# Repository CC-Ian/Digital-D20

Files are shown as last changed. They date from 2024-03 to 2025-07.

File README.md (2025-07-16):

# Big Electronic D20

This project began several years ago, before pixel dice became widely available. Inspired by existing designs but aiming for something unique, this marks my first foray into PCB art. By adding artwork to the solder mask layer, the FR4 substrate is exposed, allowing light to shine through. Combined with a 3D-printed frame, a mainboard featuring LEDs, and an IMU, the result is a visually striking D20 that comes to life when rolled.

## Showcase

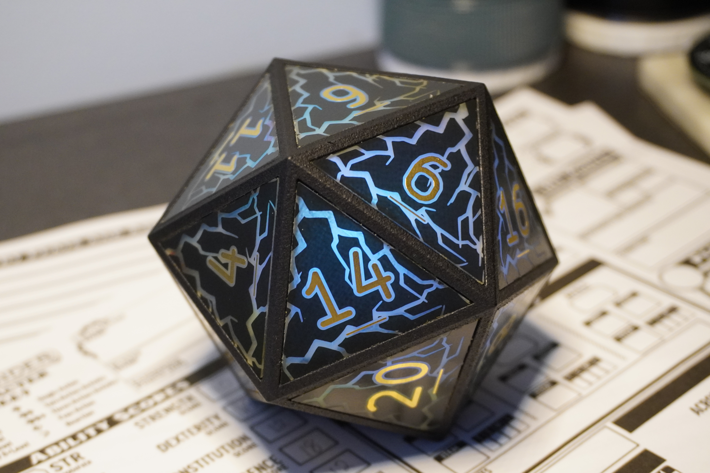
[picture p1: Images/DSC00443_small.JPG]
Atop a Character Sheet

Green Lightning Effect
Pink Lightning Effect

## Faces

- Each face is an equilateral triangle, 1.5" per edge.
- Single-sided PCBs with gold-plated numbers.
- Solder mask is relieved around each number for clear illumination.
- Lightning patterns are masked out for added visual interest.
- Designs were refined following prototype testing with various patterns.

## Frame

- Constructed from MJF-printed nylon in an icosahedral shape.
- Features inset shelves for gluing PCB faces.
- Includes cut-outs along two opposing spokes to accommodate the rectangular mainboard.

## Mainboard

- STM32L412KB microcontroller.
- LIS2DW12 MEMS IMU.
- 32 addressable LEDs.
- Voltage regulators and LiPo battery charging circuitry.
- Ultra-low power design: enters deep sleep mode when not in use.

### Operation

- The IMU detects motion, waking the microcontroller.
- LEDs activate and display a lightning animation while the die is in motion.
- The IMU is regularly polled during animation.
- When the die comes to rest, a final measurement determines the top face using cosine similarity.
- The face value determines the display color: pure red for 1, pure green for 20, with a linear gradient for intermediate values.
- The color is shown for a few seconds before returning to sleep mode.

### Power Consumption

- At rest: ~5μA, yielding a theoretical shelf life of ~5 years with a 400mAh battery.
- During operation: ~50mA, for a theoretical runtime of ~10 hours.
- Designed for intermittent use, suitable for multiple gaming sessions per charge.

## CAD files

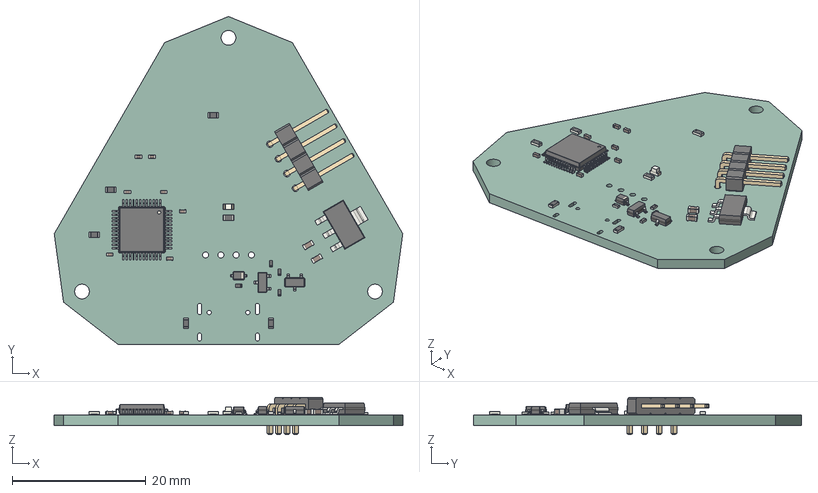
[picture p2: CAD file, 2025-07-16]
BaseStation/BaseStation.step
52.1 x 49.0 x 5.54 mm
R_0402_1005Metric x 4
C_0402_1005Metric x 7
R_0603_1608Metric x 6
C_0603_1608Metric x 2
LED_0603_1608Metric
SOT_223
SOT_23 x 2
LQFP_48_7x7mm_P05mm
D_SOD_323
PinHeader_1x04_P254mm_Horizontal
_autosave-BaseStation_PCB

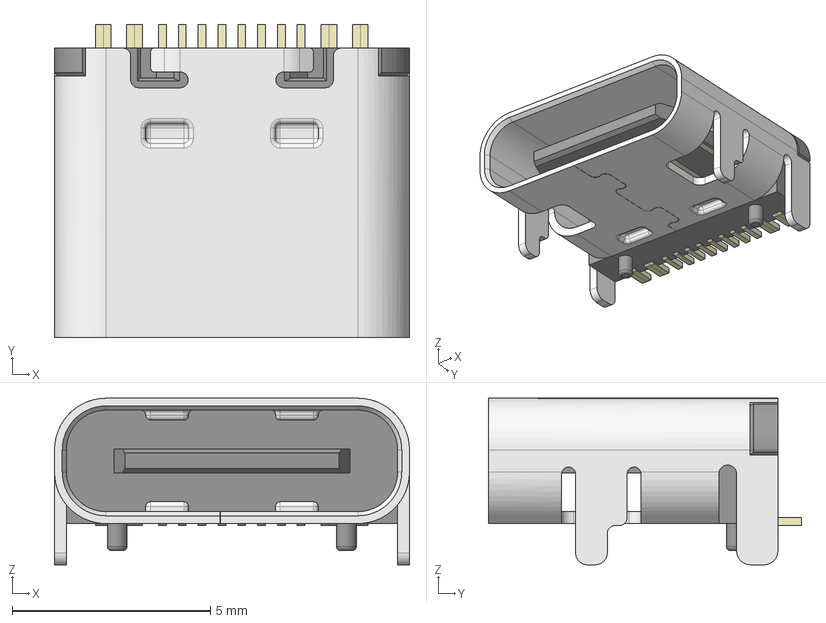
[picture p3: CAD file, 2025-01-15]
BaseStation/BaseStation/HRO_TYPE-C-31-M-12.step
8.95 x 7.90 x 4.20 mm

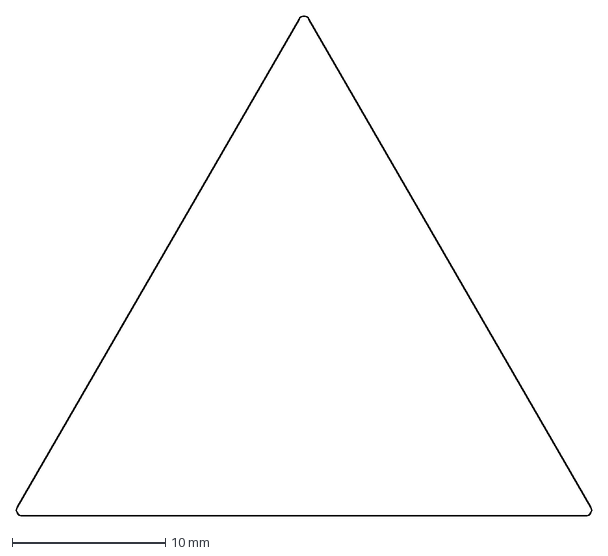
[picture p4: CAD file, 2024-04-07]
Faces/Tile Outline 1.5.dxf
37.6 x 32.6 mm

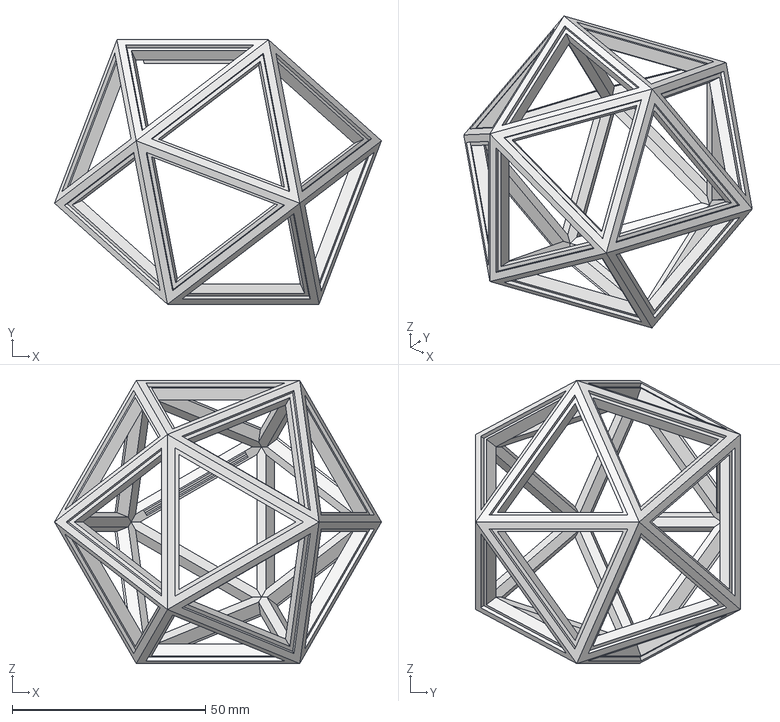
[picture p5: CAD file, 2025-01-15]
Frame/Electronic D20 Final.stp
84.7 x 68.5 x 73.3 mm

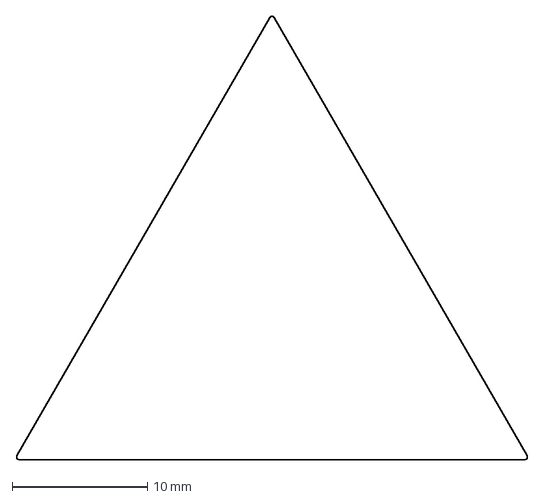
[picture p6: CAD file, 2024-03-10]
Mainboard/triangle tile outline.dxf
37.8 x 32.8 mm

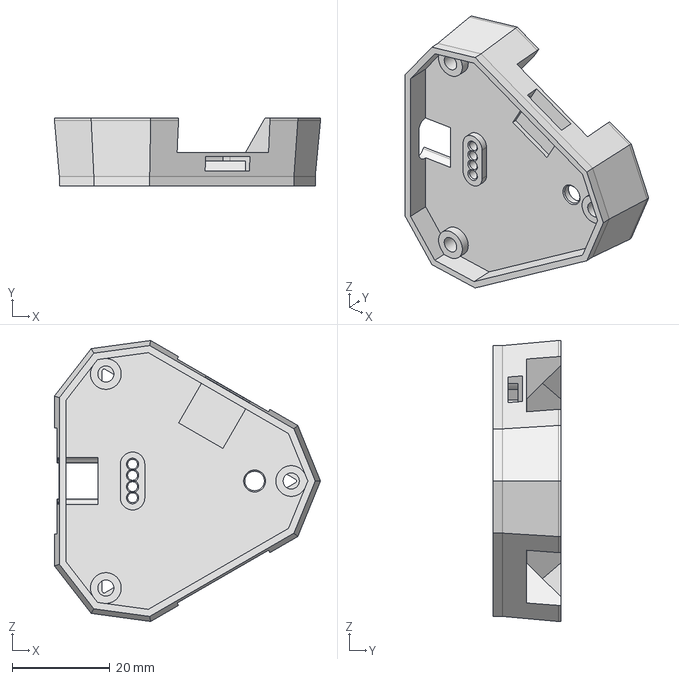
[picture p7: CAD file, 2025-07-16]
BaseStation/Base Station V2.step
54.5 x 14.0 x 57.5 mm

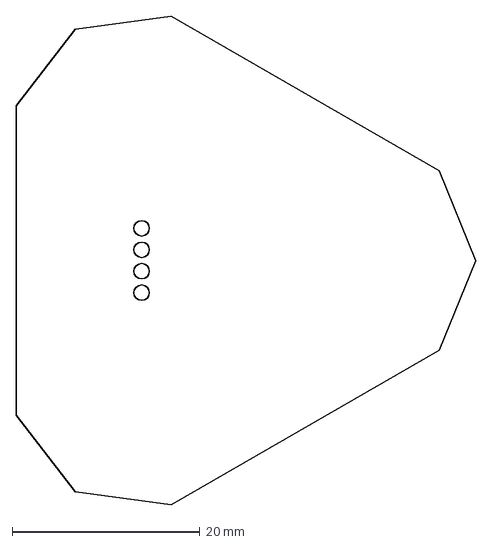
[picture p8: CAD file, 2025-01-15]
BaseStation/BaseStation/Board Outline.dxf
49.0 x 52.1 mm

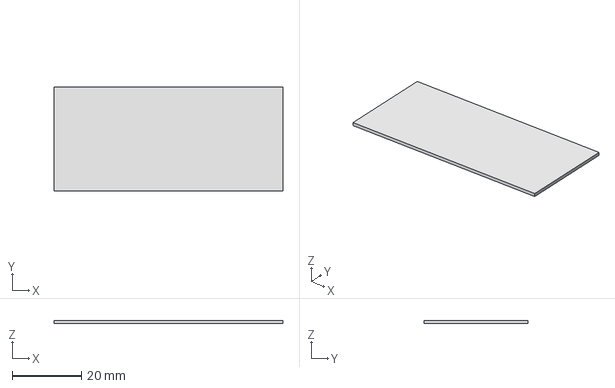
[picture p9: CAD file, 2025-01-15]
Frame/fake PCB.stp
66.3 x 30.0 x 1.00 mm

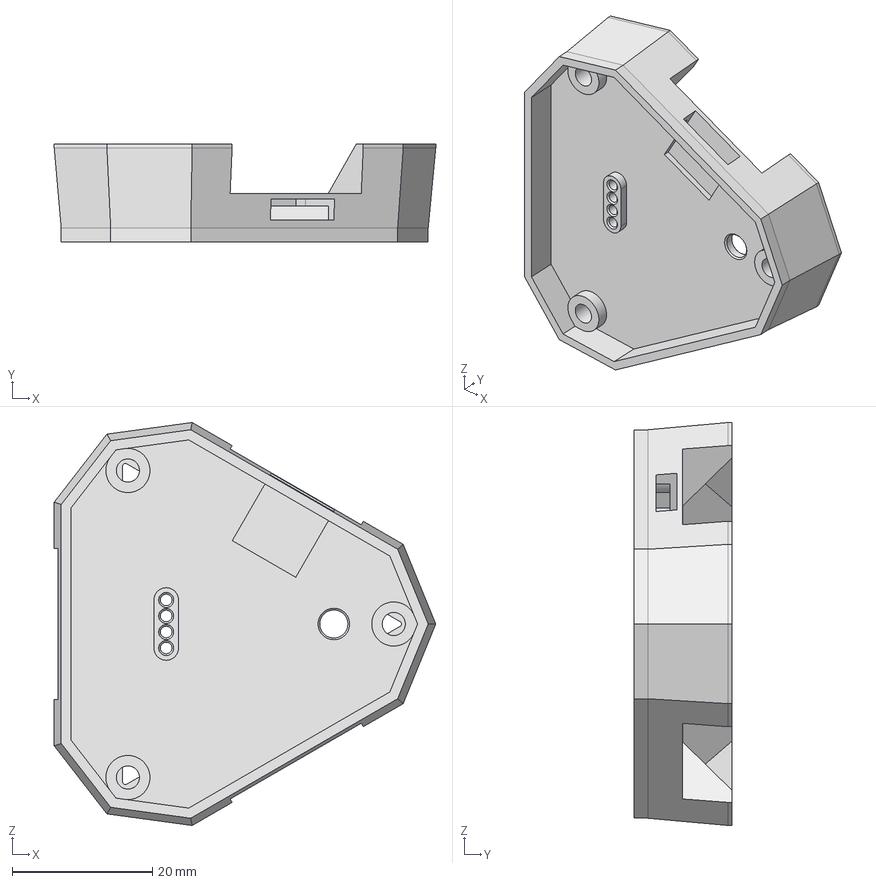
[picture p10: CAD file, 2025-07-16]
BaseStation/Base Station V1.stp
54.5 x 14.0 x 57.5 mm

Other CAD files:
BaseStation/BaseStation.ipt

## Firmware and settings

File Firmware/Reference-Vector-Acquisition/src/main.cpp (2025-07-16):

#include <Arduino.h>
#include <Adafruit_NeoPixel.h>
#include <Wire.h>

// LIS2DW12 register addresses
#define LIS2DW12_I2C_ADDRESS 0x19
#define LIS2DW12_REG_CTRL1 0x20
#define LIS2DW12_REG_CTRL2 0x21
#define LIS2DW12_REG_CTRL4_INT1_PAD_CTRL 0x23
#define LIS2DW12_REG_CTRL6 0x25
#define LIS2DW12_REG_CTRL7 0x3F
#define LIS2DW12_REG_WAKE_UP_THS 0x34
#define LIS2DW12_REG_WAKE_UP_DUR 0x35

#define NUM_READINGS 6

// BQ21080 BMS Registers
#define BMS_ADDRESS 0x6A
#define BMS_REG_ICHG_CTRL 0x04
#define BMS_STAT_PIN PA5

// Neopixel configs
#define NUM_LEDS 32
#define LED_DATA_PIN PA7
#define LED_BRIGHTNESS 200
#define LED_ENABLE PA6


// IMU Structure
struct Acceleration {
  int16_t x;
  int16_t y;
  int16_t z;
};


/// @brief IMU Reference Vectors. 0th index corresponds to the 1 face. It's inverse, the 20.
int32_t referenceVectors[][3] = {
  {112, -5392, 14652},    // 1-20
  {9696, 8276, -9236},    // 2-19
  {-5960, -14796, -356},  // 3-18
  {-6512, 14676, 408},    // 4-17
  {9376, 9048, 9792},     // 5-16
  {-15384, 212, -5200},   // 6-15
  {9308, -9392, 8884},    // 7-14
  {-464, -6476, -14828},  // 8-13
  {-15200, 1672, 5480},   // 9-12
  {8676, -10664, -9188}   // 10-11
};

// Use adafruit_neopixel to handle the WS2812B RGB LEDs onboard.
Adafruit_NeoPixel pixels = Adafruit_NeoPixel(NUM_LEDS, LED_DATA_PIN, NEO_GRB + NEO_KHZ800);

// Cyan, Turquoise, Blue, Violet. Pulled from FastLED. I think the violet is wrong? Will have to crosscheck.
// TODO: Cross-check LED Colors here.
uint32_t colorPalette[] = {65535, 4251856, 255, 15631086};

// Prototypes
void SystemClock_Config(void);
void SystemPower_Config(void);

/// @brief Enable WKUP 1 and WKUP4 pins on a rising edge.
void configureWakeupPins(bool shake = true, bool charge = true) {
  // GPIO 1 (WKUP1) [PA0]
  GPIO_InitTypeDef GPIO_InitStruct = {0};
  __HAL_RCC_GPIOA_CLK_ENABLE();
  GPIO_InitStruct.Pin = GPIO_PIN_1;
  GPIO_InitStruct.Mode = GPIO_MODE_INPUT;
  GPIO_InitStruct.Pull = GPIO_PULLDOWN;
  HAL_GPIO_Init(GPIOA, &GPIO_InitStruct);

  // GPIO 3 (WKUP4) [PA2]
  GPIO_InitStruct.Pin = GPIO_PIN_3;
  GPIO_InitStruct.Mode = GPIO_MODE_INPUT;
  GPIO_InitStruct.Pull = GPIO_PULLDOWN;
  HAL_GPIO_Init(GPIOA, &GPIO_InitStruct);
    
  /* Disable used wakeup source: PWR_WAKEUP_PIN1 */
  HAL_PWR_DisableWakeUpPin(PWR_WAKEUP_PIN1);
  HAL_PWR_DisableWakeUpPin(PWR_WAKEUP_PIN4);

  /* Clear all related wakeup flags */
  __HAL_PWR_CLEAR_FLAG(PWR_FLAG_WU);
    
  /* Enable wakeup pins WKUP1 and WKUP4 */
  if (shake) {
    HAL_PWR_EnableWakeUpPin(PWR_WAKEUP_PIN1_HIGH);
  }

  if (charge) {
    HAL_PWR_EnableWakeUpPin(PWR_WAKEUP_PIN4_HIGH);
  }

  /* Set TAMP back-up register TAMP_BKP31R to indicate
       later on that system has entered shutdown mode  */
  WRITE_REG( TAMP->BKP31R, 0x1 );
}


/// @brief Calculate the mean of an input array.
/// @param data The array to compute the mean of.
/// @return The Mean.
int calculateMean(int16_t data[]) {
  int64_t sum = 0;
  int size = sizeof(data) / sizeof(data[0]);

  for (int i = 0; i < size; i++) {
    sum += data[i];
  }

  return sum / size;
}

/// @brief 
/// @param data 
/// @return 
int calculateAbsMax(int16_t data[]) {
  int max = 0;
  int size = sizeof(data) / sizeof(data[0]);

  for (int i = 0; i < size; i++) {
    if (abs(data[i]) >= abs(max)) {
      max = abs(data[i]);
    }
  }
  
  return max;
}

/// @brief 
/// @param data 
/// @return 
int calculateAbsMin(int16_t data[]) {
  int min = 32768;
  int size = sizeof(data) / sizeof(data[0]);

  for (int i = 0; i < size; i++) {
    if (abs(data[i]) <= min) {
      min = abs(data[i]);
    }
  }
  
  return min;
}

/// @brief Computes the standard deviation of an array of data.
/// @param data The Array to compute the standard deviation of. (1D)
/// @return Standard Deviation as an integer.
int calculateStandardDeviation(int16_t data[]) {
  // Initial Declarations. Need Size and Mean to find the stdev.
  int variance = 0;
  int size = sizeof(data) / sizeof(data[0]);
  int mean = calculateMean(data);

  // Loop through each element of the array and add (value - mean)^2
  // I think this is more efficient than using actual square functions or the carrot.
  // It also might just get compiled out.
  for (int i = 0; i < size; i++) {
    variance += (data[i] - mean) * (data[i] - mean);
  }

  // Return the stdev.
  return sqrt(variance / size);
}

/// @brief Performs the dot product on two input vectors (3D).  
/// @brief https://en.wikipedia.org/wiki/Dot_product
/// @param A First Vector (3D).
/// @param B Second Vector (3D).
/// @return The Dot product of the two vectors
int64_t getDotProduct(int32_t A[3], int32_t B[3]) {
  return (A[0] * B[0]) + (A[1] * B[1]) + (A[2] * B[2]);
}

/// @brief Calculates the length of an input vector
/// @brief https://en.wikipedia.org/wiki/Magnitude_(mathematics)#Euclidean_vector_space
/// @param A Input Vector.
/// @return Magnitude of the input vector A.
int64_t getLength(int32_t A[3]) {
  return sqrt((A[0] * A[0]) + (A[1] * A[1]) + (A[2] * A[2]));
}

/// @brief Reads the acceleration data registers of the IMU.
/// @return Structure of X, Y, Z data.
Acceleration ReadAccelerometer() {
  Acceleration accel;

    Wire.beginTransmission(0x19); // initiate transmission with LIS2DW12
    Wire.write(0x28); // select register 0x0F to read from
    Wire.endTransmission(false); // false to not release the bus

    // request 6 bytes of data (X, Y, Z for acceleration)
    Wire.requestFrom(0x19, 6); 
    if (Wire.available() >= 6) {
      // combine the two bytes for X value
      accel.x = Wire.read() | (Wire.read() << 8); 
      // do the same for the Y and Z values
      accel.y = Wire.read() | (Wire.read() << 8);
      accel.z = Wire.read() | (Wire.read() << 8);
    }

  return accel;
}

/// @brief Compute the rolled value using an input vector.
/// @param measurement The input vector to compare against the references.
/// @return The number rolled [1-20] or 0 if no matching vector was found.
int computeRoll(Acceleration measurement) {
  // Create a vector from the input structure.
  int32_t measureVector[3];
  measureVector[0] = measurement.x;
  measureVector[1] = measurement.y;
  measureVector[2] = measurement.z;

  // Length of the input vector. No need to re-compute every loop.
  int64_t measureLength = getLength(measureVector); 

  for (int i = 0; i < sizeof(referenceVectors) / sizeof(referenceVectors[0]); i++) {
    int64_t referenceLength = getLength(referenceVectors[i]);
    int64_t dotProduct = getDotProduct(measureVector, referenceVectors[i]);
    float cosine = float(dotProduct) / float(referenceLength * measureLength);

    // Accept close enough values as our number. This does have some deadzone, but that is preferable to noting the wrong roll.
    // Magic number. I found that the values intersect somewhere around 0.95 I think. Don't want to deal with intersecting values, so we get this instead.
    if (cosine >= 0.975) {
      return (1 + i);     // makes 1 to 10.
    } else if (cosine <= -0.975) {
      return (20 - i);    // makes 20 to 11
    }
  }

  // Invalid roll. Die cocked or non-level surface.
  return 0;
}


/// @brief Fade all LEDs over the input duration.
/// @param duration Input Duration.
void fadeAllPixels(int duration) {
  // Set brightness each loop?
  // want 60FPS
  // duration in milliseconds
  // need a step every 17ms.
  int numSteps = duration / 17;
  int brightness = pixels.getBrightness();
  int brightnessStep = brightness / numSteps;

  // Perform the brightness step operation
  for (int i = 0; i < numSteps; i++) {
    pixels.setBrightness(brightnessStep);
    brightness -= brightnessStep;
    if (brightness < 0) {
      brightness = 0;
    }
    pixels.show();
    HAL_Delay(17);
  }

  // Clean up. Set strip to black and restore brightness.
  pixels.clear();
  pixels.setBrightness(LED_BRIGHTNESS);
}


/// @brief Initialize the IMU to low power, low ODR mode, and enable wakeup interrupt.
void initIMU() {

  // // Reset all control registers. Used to unbrick device?
  // Wire.beginTransmission(LIS2DW12_I2C_ADDRESS);
  // Wire.write(LIS2DW12_REG_CTRL2);
  // Wire.write(0b01000100);
  // Wire.endTransmission();

  // TODO: May wish to replace wakeup with tap interrupt. Was more responsive during testing.
  // Ctrl 1 to 0x10. 1.6Hz, Low Power.
  Wire.beginTransmission(LIS2DW12_I2C_ADDRESS);
  Wire.write(LIS2DW12_REG_CTRL1);
  Wire.write(0x10);
  Wire.endTransmission();
  HAL_Delay(10);

  // ctrl 7 to 0x20. Enable Interrupts.
  Wire.beginTransmission(LIS2DW12_I2C_ADDRESS);
  Wire.write(LIS2DW12_REG_CTRL7);
  Wire.write(0x20);
  Wire.endTransmission();  

  // Set wakeup duration to zero? (One sample above threshold)
  Wire.beginTransmission(LIS2DW12_I2C_ADDRESS);
  Wire.write(LIS2DW12_REG_WAKE_UP_DUR);
  Wire.write(0x00);
  Wire.endTransmission();

  // A high wakeup threshold so it only kicks on when it's being rolled?
  Wire.beginTransmission(LIS2DW12_I2C_ADDRESS);
  Wire.write(LIS2DW12_REG_WAKE_UP_THS);
  Wire.write(0x0F);
  Wire.endTransmission();

  // Set Interrupt1 to pulse wakeup signal.
  Wire.beginTransmission(LIS2DW12_I2C_ADDRESS);
  Wire.write(LIS2DW12_REG_CTRL4_INT1_PAD_CTRL);
  Wire.write(0x20);
  Wire.endTransmission();
}

/// @brief DEPRECATED; Init BMS to 250mA charge current.  
/// @brief DEPRECATED; https://www.ti.com/lit/ds/symlink/bq21080.pdf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
void initBMS() {
  Wire.beginTransmission(BMS_ADDRESS);
  Wire.write(BMS_REG_ICHG_CTRL);
  Wire.write(0x30); // Enable charging, charge current 210mA.
  Wire.endTransmission();
}


/// @brief Setup runs from the beginning every time we wake up. Need to check the wakeup source when woken from shutdown.  
/// @brief INIT IMU to 12.5HZ low power. Init BMS to 250mA charge current.  
/// @brief Begin Lightning animation and read acceleration data into a moving average.  
/// @brief Compute standard deviation of the moving average. When it falls off, we know motion has stopped.  
/// @brief Compute the roll based off gravity and the reference vectors.    
/// @brief Pulse the appropriate color for the roll.  
/// @brief Re-configure IMU and wakeup pins.  
/// @brief Shutdown.  
void setup() {
  
  HAL_Init();

  SystemClock_Config();

  SystemPower_Config();

  // LED stuff. Active Low.
  pinMode(LED_ENABLE, OUTPUT);
  digitalWrite(LED_ENABLE, HIGH);

  // WAKEUP4. Connected to Vin.
  pinMode(PA2, INPUT_PULLDOWN);
  

  // Slight delay in startup for settle and timing.
  HAL_Delay(100);

  // Initialize IMU in wake mode. Higher current draw, for more readings per second.
  Wire.setSCL(PB6); // Set Clock pin.
  Wire.setSDA(PB7); // Set Data Pin.
  Wire.begin();

  initIMU();
  // initBMS();

}


/// @brief Required for the arduino framework. Code never reaches this point.
void loop() {
  Acceleration accel = ReadAccelerometer();
  delay(1000); // Wait for a second
}

/// @brief SystemClock Config ripped from a sample st project. Seems to work.  
/// @brief https://github.com/STMicroelectronics/STM32CubeL4/blob/d3b7dcfb72c6c6a046862654ef6e23cbed9935a8/Projects/NUCLEO-L412KB/Examples/PWR/PWR_SHUTDOWN/Src/main.c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
void SystemClock_Config(void) {
  // TODO: Double check that this can't be made more efficient. APPNOTE on this.
  RCC_ClkInitTypeDef RCC_ClkInitStruct = {0};
  RCC_OscInitTypeDef RCC_OscInitStruct = {0};

  /* MSI is enabled after System reset, activate PLL with MSI as source */
  RCC_OscInitStruct.OscillatorType = RCC_OSCILLATORTYPE_MSI;
  RCC_OscInitStruct.MSIState = RCC_MSI_ON;
  RCC_OscInitStruct.MSIClockRange = RCC_MSIRANGE_6;
  RCC_OscInitStruct.MSICalibrationValue = RCC_MSICALIBRATION_DEFAULT;
  RCC_OscInitStruct.PLL.PLLState = RCC_PLL_ON;
  RCC_OscInitStruct.PLL.PLLSource = RCC_PLLSOURCE_MSI;
  RCC_OscInitStruct.PLL.PLLM = 1;
  RCC_OscInitStruct.PLL.PLLN = 40;
  RCC_OscInitStruct.PLL.PLLR = 2;
  RCC_OscInitStruct.PLL.PLLQ = 4;
  if(HAL_RCC_OscConfig(&RCC_OscInitStruct) != HAL_OK)
  {
    /* Initialization Error */
    // TODO: Find a way to reset the chip if this occurs? Due to the structure of this, 
    // this will PERMANANTLY lock up the die if this happens.
    while(1);
  }

  
  /* Select PLL as system clock source and configure the HCLK, PCLK1 and PCLK2 
     clocks dividers */
  RCC_ClkInitStruct.ClockType = (RCC_CLOCKTYPE_SYSCLK | RCC_CLOCKTYPE_HCLK | RCC_CLOCKTYPE_PCLK1 | RCC_CLOCKTYPE_PCLK2);
  RCC_ClkInitStruct.SYSCLKSource = RCC_SYSCLKSOURCE_PLLCLK;
  RCC_ClkInitStruct.AHBCLKDivider = RCC_SYSCLK_DIV1;
  RCC_ClkInitStruct.APB1CLKDivider = RCC_HCLK_DIV1;  
  RCC_ClkInitStruct.APB2CLKDivider = RCC_HCLK_DIV1;  
  if(HAL_RCC_ClockConfig(&RCC_ClkInitStruct, FLASH_LATENCY_4) != HAL_OK)
  {
    /* Initialization Error */
    // TODO: Find a way to reset the chip if this occurs? Due to the structure of this, 
    // this will PERMANANTLY lock up the die if this happens.
    while(1);
  }
}


void SystemPower_Config(void) {
  /* Enable Power Control clock */
  __HAL_RCC_PWR_CLK_ENABLE();
  
  /* Enable writing TAMP back-up registers */
  HAL_PWR_EnableBkUpAccess();

}

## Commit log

2024-02-06 Initial test board. 6L to abuse jlc
    [Digital D20-B_Cu.gbr, Digital D20-B_Mask.gbr, Digital D20-B_Paste.gbr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]
2024-02-06 Add 'jlcjlcjlcjlc' to mark order number placement.
    [Digital D20-B_Cu.gbr, Digital D20-B_Mask.gbr, Digital D20-B_Paste.gbr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]
2024-03-07 The test board I ordered
    [Digital D20-B_Cu.gbr, Digital D20-B_Mask.gbr, Digital D20-B_Paste.gbr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]
2024-03-07 Clear out old files
    [Digital D20-B_Cu.gbr, Digital D20-B_Mask.gbr, Digital D20-B_Paste.gbr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]
2024-03-07 Begin layout. IMU, BMS, Sys_REG all complete. Working MCU.
    [mainboard.kicad_pcb, mainboard.kicad_sch]
2024-03-10 Diode layout, majority of schema, tile thoughts
    [mainboard.kicad_pcb, mainboard.kicad_sch, triangle tile outline.dxf]
2024-03-13 Rev A layout. pending review
    [mainboard.kicad_pcb, mainboard.kicad_sch, mainboard_copy Mar 12.kicad_pcb]
2024-03-16 Rev 0 layout complete. ORdering as protoptype.
    [mainboard-B_Cu.gbr, mainboard-B_Mask.gbr, mainboard-B_Paste.gbr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]
2024-04-03 re-org project. This is how it should've been from the start.
    [mainboard-B_Cu.gbr, mainboard-B_Mask.gbr, mainboard-B_Paste.gbr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]
2024-04-06 Updates to firmware. Suspect bad mean/stdev calculations
    [mainboard.kicad_pcb, mainboard.kicad_sch]
2024-04-06 Use All 32 LEDs, better stdev and mean math which doesn't hit a global.
    [main.cpp]
2024-04-06 Something to do with the i2c device test
2024-04-07 Pull in faces. Begin modifying schema.
    [Faces-B_Cu.gbr, Faces-B_Mask.gbr, Faces-B_Paste.gbr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]
2024-04-09 Increase LED Brightness, Add free fall and impact guarding to main calculation loop.
2024-04-10 Re-tool faces. It costs nothing to add the extra panelization holes. They bill this as 20 designs regardless.
    [Faces-B_Cu.gbr, Faces-B_Mask.gbr, Faces-B_Paste.gbr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]
2024-04-10 Begin the base station layout (BMP)
    [BaseStation.kicad_pcb, BaseStation.kicad_sch]
2025-01-15 Somewhere around the first complete prototype. time to change BMS
    [BaseStation-B_Cu.gbr, BaseStation-B_Mask.gbr, BaseStation-B_Paste.gbr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]
2025-02-07 New Hardware; LED data moved from PA4 to PA7
2025-02-07 New hardware; attempt to correct BMS failures, better layout and routing, bom only change to allow swap to USB DFU Bootloader/upload
    [bms.kicad_sch, leds.kicad_sch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]
2025-07-16 V2 mainboard, some firmware stuffs, free design files I guess
    [Base Station V1.stp, Base Station V2.step, BaseStation.ipt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]
